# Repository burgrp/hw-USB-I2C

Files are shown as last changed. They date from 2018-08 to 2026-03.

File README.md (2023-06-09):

# USB-I2C bridge

USB to I2C bridge implemented on ESP32-C3FN4 MCU.

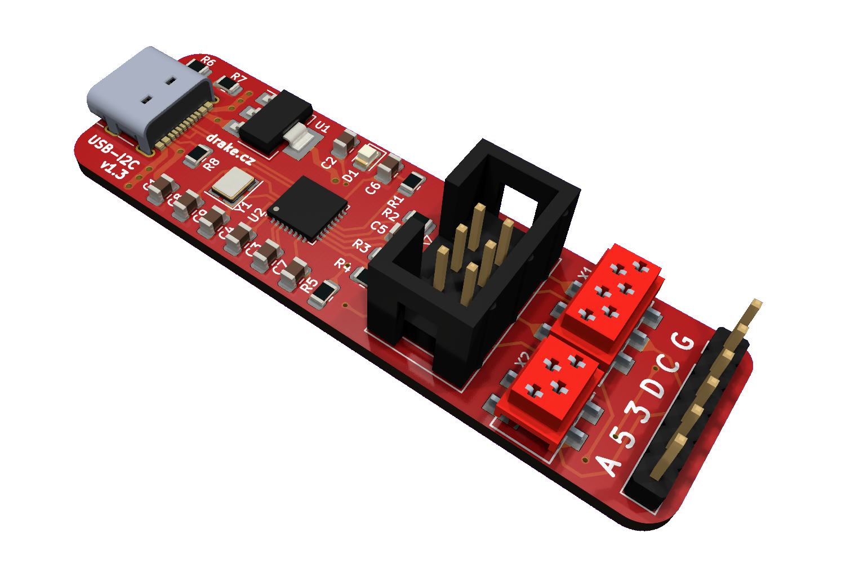
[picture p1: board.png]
board


## Features

- Serial to I2C interface
- Alert line
- 3.3V, 5V power supply
- Simple serial protocol
- Implemented in MicroPython
- Designed in KiCAD

## Connectors

All connectors have the same pin-out as follows.

1. GND
2. SCL
3. SDA
4. +3.3 V
5. +5V
6. ALERT (IRQ)

## Binding

For Node.js there is a library [i2c-js](https://github.com/burgrp/i2c-js) published on NPM as [@burgrp/i2c](https://www.npmjs.com/package/@burgrp/i2c).

## USB protocol

- VID: 303A
- PID: 1001

The bridge is controlled through serial port by simple text protocol:

- `S` scans bus for devices, replies `Saddr1,addr2,addr3,...`
- `R,addr,len` reads data from device, replies `R,hex_data`
- `W,addr,hex_data` writes data to device, replies `W,acked_count`
- `A` gets alert line status, replies `AT` (true) or `AF` (false).

Addresses are always expressed in 7bit format, therefore without R/W bit.

### Example

By commands `S`, `R,79,2`, `A` we can scan the bus, read temperature from LM75A sensor found on address 79 and check the alert line:

```
> miniterm /dev/ttyACM0 115200 --raw
--- Miniterm on /dev/ttyACM0  115200,8,N,1 ---
--- Quit: Ctrl+] | Menu: Ctrl+T | Help: Ctrl+T followed by Ctrl+H ---
S
S79
R,79,2
R1A40
A
AF
```

## License
This work is licensed under a Creative Commons Attribution-ShareAlike 4.0 International License.

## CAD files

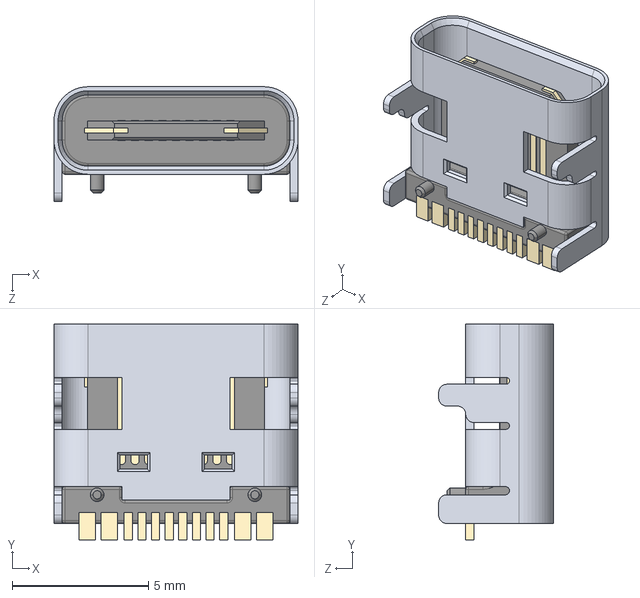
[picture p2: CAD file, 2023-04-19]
board/USB Type C Port (SMD Type).STEP
8.94 x 7.90 x 4.20 mm

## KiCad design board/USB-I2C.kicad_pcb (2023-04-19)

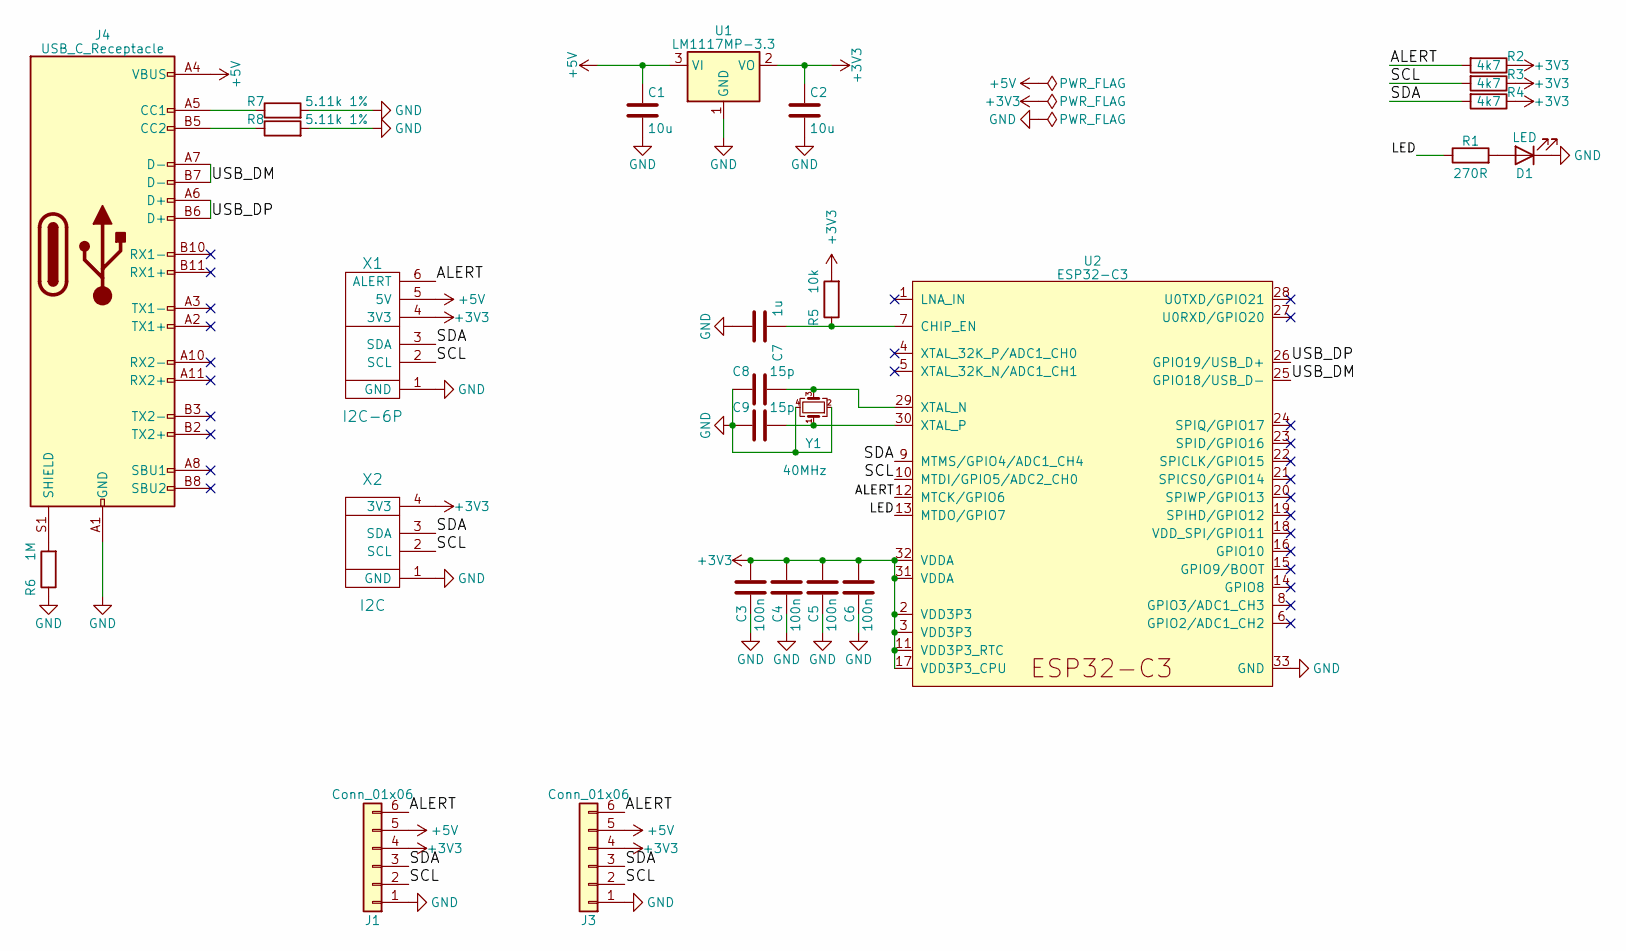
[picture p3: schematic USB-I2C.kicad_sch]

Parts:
C1, C2: 10u; C_0805_2012Metric
C3, C4, C5, C6: 100n; C_0805_2012Metric
C7: 1u; C_0805_2012Metric
C8, C9: 15p; C_0805_2012Metric
D1: LED; LED_0805_2012Metric
J1: Conn_01x06; PinHeader_1x06_P2.54mm_Vertical
J3: Conn_01x06; IDC-Header_2x03_P2.54mm_Vertical
J4: USB_C_Receptacle; USB_C_Receptacle_G-Switch_GT-USB-7010ASV
R1: 270R; R_0805_2012Metric
R2, R3, R4: 4k7; R_0805_2012Metric
R5: 10k; R_0805_2012Metric
R6: 1M; R_0805_2012Metric
R7, R8: 5.11k 1%; R_0805_2012Metric
U1: LM1117MP-3.3; SOT-223-3_TabPin2
U2: ESP32-C3; QFN-32-1EP_5x5mm_P0.5mm_EP3.45x3.45mm
X1: I2C-6P; Micro-Match-FOB-6
X2: I2C; Micro-Match-FOB-4
Y1: 40MHz; Crystal_SMD_3225-4Pin_3.2x2.5mm

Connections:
+3V3: C2.1, C3.1, C4.1, C5.1, C6.1, J1.4, J3.4, R2.1, R3.1, R4.1, R5.2, U1.2 (VO), U2.2 (VDD3P3), U2.3 (VDD3P3), U2.11 (VDD3P3_RTC), U2.17 (VDD3P3_CPU), U2.31 (VDDA), U2.32 (VDDA), X1.4 (3V3), X2.4 (3V3)
+5V: C1.1, J1.5, J3.5, J4.A4 (VBUS), J4.A9 (VBUS), J4.B4 (VBUS), J4.B9 (VBUS), U1.3 (VI), X1.5 (5V)
/ALERT: J1.6, J3.6, R2.2, U2.12 (MTCK/GPIO6), X1.6 (ALERT)
/LED: R1.1, U2.13 (MTDO/GPIO7)
/SCL: J1.2, J3.2, R3.2, U2.10 (MTDI/GPIO5/ADC2_CH0), X1.2 (SCL), X2.2 (SCL)
/SDA: J1.3, J3.3, R4.2, U2.9 (MTMS/GPIO4/ADC1_CH4), X1.3 (SDA), X2.3 (SDA)
/USB_DM: J4.A7 (D-), J4.B7 (D-), U2.25 (GPIO18/USB_D-)
/USB_DP: J4.A6 (D+), J4.B6 (D+), U2.26 (GPIO19/USB_D+)
GND: C1.2, C2.2, C3.2, C4.2, C5.2, C6.2, C7.1, C8.1, C9.1, D1.1 (K), J1.1, J3.1, J4.A1 (GND), J4.A12 (GND), J4.B1 (GND), J4.B12 (GND), R6.1, R7.2, R8.2, U1.1 (GND), U2.33 (GND), X1.1 (GND), X2.1 (GND), Y1.2, Y1.4
unnamed: D1.2 (A), R1.2
unnamed: J4.A5 (CC1), R7.1
unnamed: J4.B5 (CC2), R8.1
unnamed: J4.S1 (SHIELD), R6.2
unnamed: C7.2, R5.1, U2.7 (CHIP_EN)
unnamed: C8.2, U2.29 (XTAL_N), Y1.3
unnamed: C9.2, U2.30 (XTAL_P), Y1.1

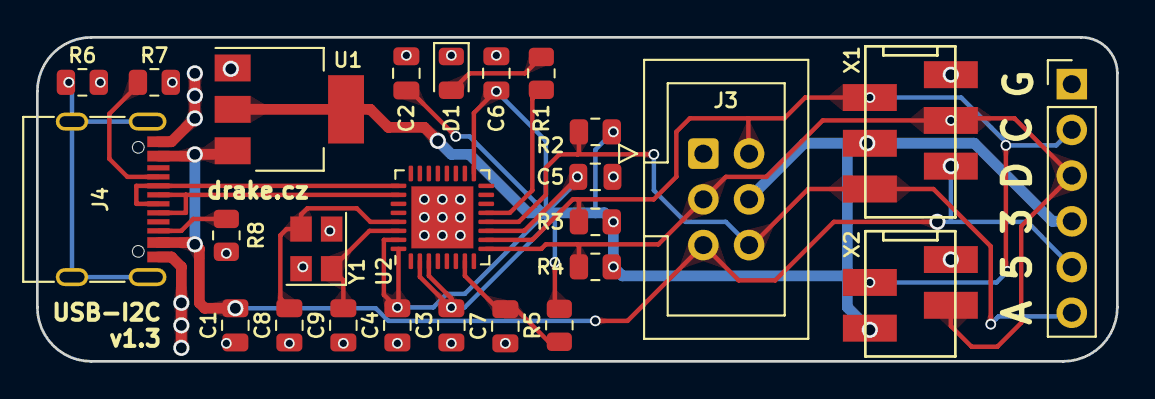
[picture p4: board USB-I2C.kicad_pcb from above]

Board: 2 copper layers, 60.0 x 18.0 mm, 26 parts (0 on the bottom side), 16 nets.

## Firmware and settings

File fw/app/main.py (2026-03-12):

from machine import Pin, UART, I2C
import binascii

led = Pin(7, Pin.OUT)
alert = Pin(6, Pin.IN, Pin.PULL_UP)

i2c = I2C(0, scl = Pin(5), sda = Pin(4), freq = 100000)

commands = {
    "S": lambda: ",".join(str(addr) for addr in i2c.scan()),
    "R": lambda addr, len: binascii.hexlify(i2c.readfrom(int(addr), int(len))).decode("ascii"),
    "W": lambda addr, data: i2c.writeto(int(addr), binascii.unhexlify(data)),
    "A": lambda: str("F" if alert.value() == 1 else "T"),
    "F": lambda freqKHz: i2c.init(freq=int(freqKHz) * 1000)
}

def do(cmd):
    led.value(1)
    try:
        cmd = cmd.split(",")
        cmd = [x.strip() for x in cmd]

        if cmd[0] in commands:
            result = commands[cmd[0]](*cmd[1:])
            return cmd[0] + str(result)
        else:
            raise Exception("Unknown command. Try S, R, W, A.")

    finally:
        led.value(0)

# print(do("S"))
# print(do(" R , 79 , 2 "))
# print(do(" W , 79, 0000 "))
# print(do(" A "))
# print(do(" W , 10, 0000 "))

while True:
    try:
        print(do(input()))
    except Exception as e:
        print("!" + str(e))

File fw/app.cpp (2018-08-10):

target::gpio_b_f::Peripheral* LED_PORT = &target::GPIOB;
int LED_PIN = 7;

namespace i2c {
	class I2C: public applicationEvents::EventHandler {

	protected:
		target::i2c::Peripheral* peripheral;
		int length = 0;
		int index = 0;
		int stopEventId;

		void start(int address, int length, int rdWrn) {
			this->length = length;
			this->index = 0;
			peripheral->CR2.setSADD(address << 1);
			peripheral->CR2.setNBYTES(length);
			peripheral->CR2.setRD_WRN(rdWrn);
			peripheral->CR2.setSTART(1);
		}

	public:
		
		void init(target::i2c::Peripheral* peripheral) {
			this->peripheral = peripheral;
			peripheral->TIMINGR.setPRESC(1);
			peripheral->TIMINGR.setSCLL(0xC7);
			peripheral->TIMINGR.setSCLH(0xC3);
			peripheral->TIMINGR.setSDADEL(0x02);
			peripheral->TIMINGR.setSCLDEL(0x04);
			peripheral->CR2.setAUTOEND(1);
			peripheral->CR1.setRXIE(1);
			peripheral->CR1.setTXIE(1);
			peripheral->CR1.setSTOPIE(1);
			peripheral->CR1.setPE(1);
			stopEventId = applicationEvents::createEventId();
			handle(stopEventId);
		}
		
		virtual void onEvent() {
			onStop(peripheral->CR2.getRD_WRN());
		}

		void handleInterrupt() {

			if (peripheral->ISR.getRXNE()) {
				int byte = this->peripheral->RXDR.getRXDATA();
				onRx(byte, this->index++);
			}

			if (peripheral->ISR.getTXIS()) {
				peripheral->TXDR.setTXDATA(onTx(index));
			}

			if (peripheral->ISR.getSTOPF()) {				
				peripheral->ICR.setSTOPCF(1);
				applicationEvents::schedule(stopEventId);
			}
			
		}
		
		virtual void onRx(int byte, int index) {
		}

		virtual int onTx(int index) {
			return 0;
		}

		virtual void onStop(bool read) {
		}

		void read(int address, int length) {
			this->start(address, length, 1);
		}

		void write(int address, int length) {
			this->start(address, length, 0);
		}
	};

}

class TurnLedOffTimer : public genericTimer::Timer {

	void onTimer() {
		LED_PORT->ODR.setODR(LED_PIN, 0);
	}

};

TurnLedOffTimer turnLedOffTimer;

class DataEndopoint;

class ConverterI2C: public i2c::I2C {
public:

	DataEndopoint* endpoint;

	virtual void onRx(int byte, int index);
	virtual int onTx(int index);
	virtual void onStop(bool read);
};

class DataEndopoint : public usbd::AbstractBulkEndpoint {
    
public:
    
	ConverterI2C i2c;

	unsigned char i2cBuffer[64];

	void init() {
        rxBufferSize = 64;
        txBufferSize = 64;
        AbstractBulkEndpoint::init();

		this->i2c.endpoint = this;
		this->i2c.init(&target::I2C1);		
    }

    void correctTransferIn() {
    }
    
    void correctTransferOut(unsigned char* data, int len) {

		LED_PORT->ODR.setODR(LED_PIN, 1);
		turnLedOffTimer.start(10);

		if (len > 0) {
			
			bool doRead = data[0] & 1;
			int address = data[0] >> 1;
			
			if (doRead) {
				int readLen = data[1];				
				i2c.read(address, readLen);
				
			} else {
				for (int c = 0; c < len - 1; c++) {
					i2cBuffer[c] = data[c + 1];
				}
				i2c.write(address, len - 1);
			}
		}
			
        statRx(usbd::EP_VALID);		
    }

};

void ConverterI2C::onRx(int byte, int index) {
	endpoint->i2cBuffer[index] = byte;
}

int ConverterI2C::onTx(int index) {
	return endpoint->i2cBuffer[index];
}

void ConverterI2C::onStop(bool read) {
	if (read) {
		endpoint->send(endpoint->i2cBuffer, length);
	}
}


class DefaultInterface : public usbd::UsbInterface {
public:
		DataEndopoint endpoint;

		void init() {
			endpoints[0] = &endpoint;
			UsbInterface::init();
		}
};

class DefaultConfiguration : public usbd::UsbConfiguration {
public:
	DefaultInterface interface;

	void init() {
		interfaces[0] = &interface;
		maxPower = 500;
		UsbConfiguration::init();
	}
};

class ConverterDevice : public usbd::UsbDevice {
public:
	DefaultConfiguration configuration;

	void init() {		
		strProduct = "USB to I2C converter";
		strVendor ="DEVICE.FARM";
		configurations[0] = &configuration;		
		UsbDevice::init();
	}
};

ConverterDevice converterDevice;

void interruptHandlerI2C1() {
	converterDevice.configuration.interface.endpoint.i2c.handleInterrupt();
}

void initApplication() {

	genericTimer::clkHz = 48E6;

	target::RCC.AHBENR.setIOPBEN(true);
	LED_PORT->MODER.setMODER(LED_PIN, 1);
	LED_PORT->ODR.setODR(LED_PIN, 1);
	turnLedOffTimer.start(100);

	target::RCC.AHBENR.setIOPAEN(true);
	target::GPIOA.AFRH.setAFRH(9, 4);
	target::GPIOA.AFRH.setAFRH(10, 4);
	target::GPIOA.MODER.setMODER(9, 2);
	target::GPIOA.MODER.setMODER(10, 2);

	target::RCC.APB1ENR.setC_EN(1, 1);
	target::NVIC.ISER.setSETENA(1 << target::interrupts::External::I2C1);
	
	converterDevice.init();
}
